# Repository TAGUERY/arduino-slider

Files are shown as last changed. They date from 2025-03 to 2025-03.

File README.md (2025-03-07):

# Template Projet Arduino

[Vidéo démonstration](https://raw.githubusercontent.com/TAGUERY/arduino-slider/main/docs/assets/video-demo.mp4)

`Réalisé par Tristan Montanari
Option Arduino 2025 – COMEM+`

---

## Description

À l'origine, mon projet devait être un slider pour une caméra. Cependant, en prenant en compte le temps disponible, le matériel et le budget, j'ai décidé de conserver l'idée du slider mais en l'adaptant à un usage en salle de classe.

[Vidéo 1 qui m'a inspiré pour la conception](https://www.youtube.com/watch?v=4Rm1vJ67MkA&t=10s&ab_channel=GRINwood)
[Vidéo 2](https://www.youtube.com/watch?v=fR_-R2bS9ag&t=449s&ab_channel=FilmRiot)

Ce dispositif est placé sous une corbeille à papier. Les étudiants doivent essayer de jeter leurs feuilles dans la poubelle de recyclage, mais avec un défi supplémentaire : la plateforme bouge aléatoirement de droite à gauche. Elle effectue des allers-retours entre deux extrémités et deux capteurs permettent de relancer son mouvement lorsqu’elle atteint un bord.

## Documentation

Retrouvez la documentation dans le dossier [Docs](https://github.com/TAGUERY/arduino-slider/tree/main/docs)

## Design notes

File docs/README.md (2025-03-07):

# Documentation  

## Recherche et conception  

`À l’origine, je voulais créer un slider motorisé pour une caméra. Mais en prenant en compte le temps à disposition, le matériel et le budget, j’ai décidé d’adapter l’idée tout en gardant le concept du slider.`  

`Ce projet est conçu pour être installé sous une corbeille à papier. L’objectif est d’ajouter un défi lors du recyclage des feuilles : au lieu de simplement jeter le papier, les utilisateurs doivent viser une poubelle qui bouge. Le slider se déplace de manière aléatoire de droite à gauche, ce qui ajoute une difficulté supplémentaire.`  

`Le mouvement est contrôlé par un moteur et des capteurs. Il effectue des allers-retours entre deux extrémités, et un capteur détecte lorsque la plateforme atteint un bord pour la faire repartir dans l’autre sens.`  

Construction (voir les images en suivant les étapes):
1. Couper le bois en 3 parties : 2x 20x10 cm et 1x 23x20 cm.
2. Percer deux trous parallèles à mi-hauteur, d’un diamètre de 1 cm, avec un espacement d’environ 15 cm.
3. Planter 4 clous à 12 cm chacun sur la plateforme (planche de 23x20 cm) pour guider celle-ci le long des deux tubes.
4. Fixer 2 équerres (du côté des clous) pour y placer les deux capteurs avec du double-face, en veillant à ce qu’ils soient orientés vers l’extérieur.
5. Insérer les tiges dans les 2 planches de 20x10 cm.
6. Fixer les équerres et installer le moteur (écart de 31 mm entre les deux pas de vis, si c'est un NEMA 17).
7. Planter un clou avec une roue crantée, en s’assurant qu’elle puisse tourner librement.
8. Sur le profil de la plateforme, fixer une équerre avec la pince à courroie.
9. Installer la courroie. Si elle est trop courte, faire passer les tubes à travers la planche latérale pour rapprocher les deux planches.
10. Remplacer les fils des capteurs par des fils d’au moins 1 mètre, afin qu’ils puissent se déplacer avec la plateforme.

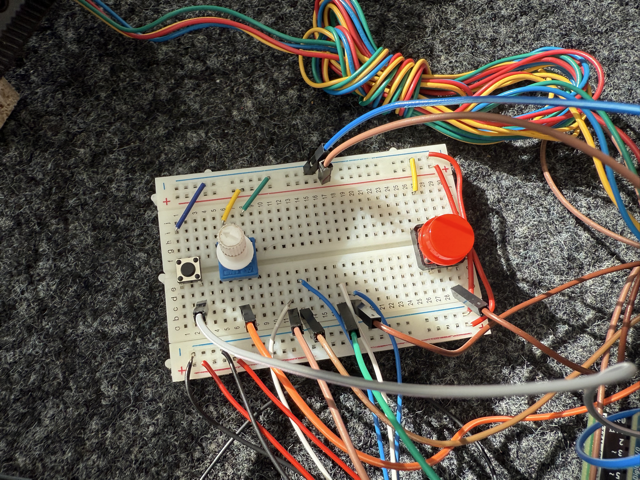
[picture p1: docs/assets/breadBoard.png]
Breadboard
  
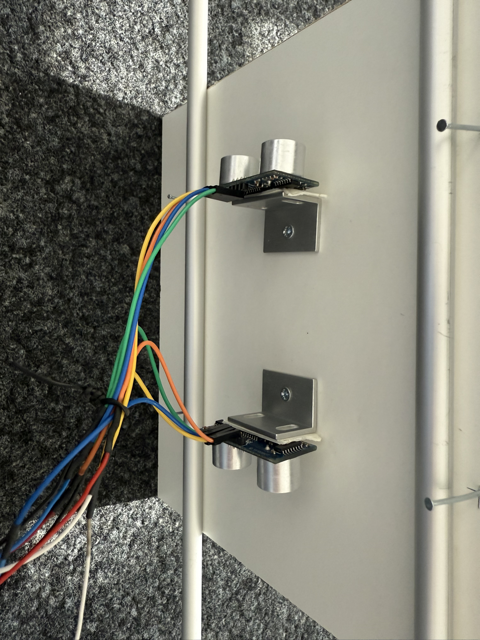
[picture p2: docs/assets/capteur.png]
capteurs sous la plateforme
  
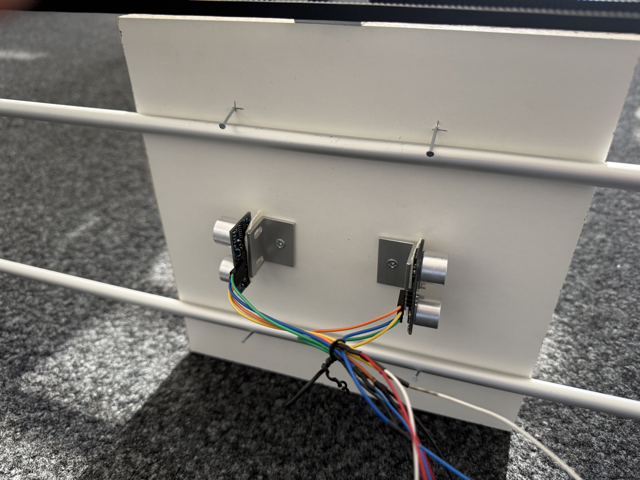
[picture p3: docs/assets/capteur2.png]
autre angle des capteurs sous la plateforme
  
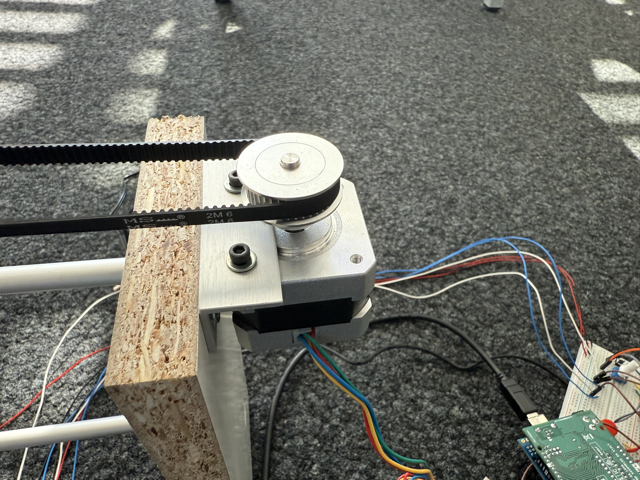
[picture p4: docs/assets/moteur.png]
moteur avec le couroie
  
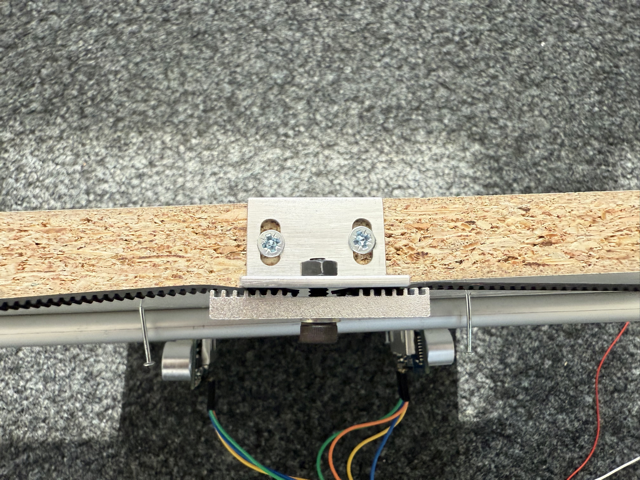
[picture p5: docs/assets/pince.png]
couroie attachée à la plateforme
  
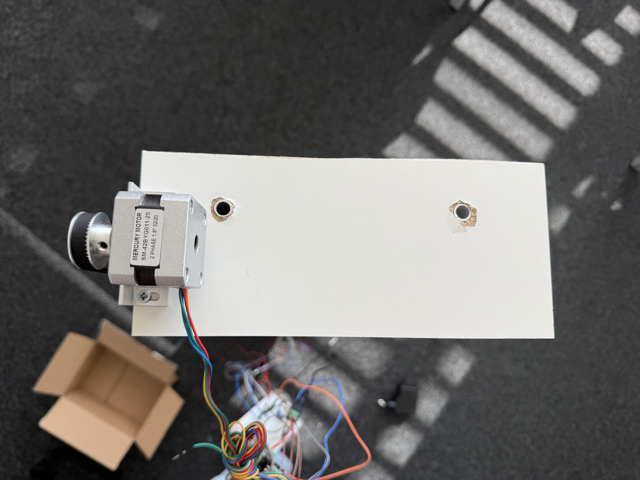
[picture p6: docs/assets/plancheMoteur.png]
moteur vissé à la planche principale
  

---

## Circuit électronique  

`Le circuit est basé sur un Arduino Uno, un moteur pas à pas et des capteurs de distance.`  

---

### Schéma  

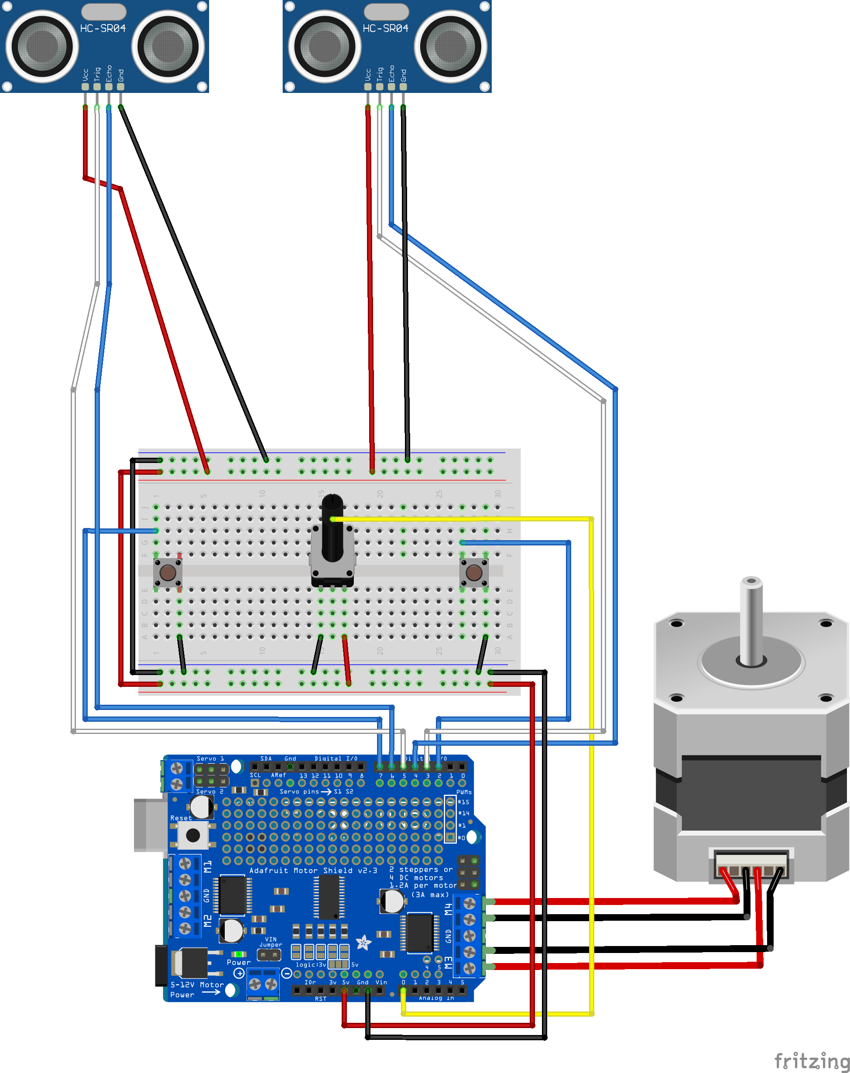
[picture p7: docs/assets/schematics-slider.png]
Schéma du circuit
  

`Attention au raccordement des fils du moteur, il faut contrôler le branchement correct des câbles avec un multimètre.`  

---

### BOM  

| Réf | Composant | Quantité | Description | Fournisseur / Lien |
| --- | --- | --- | --- | --- |
| 1 | Arduino Uno R3 | 1 | Microcontrôleur ATmega328P | [Arduino](https://store.arduino.cc/products/arduino-uno-rev3) |
| 2 | Breadboard | 1 | Plaque de prototypage | |
| 3 | HC-SR04 Sensor | 2 | Capteur de distance pour détecter les bords | [Distrelec](https://www.distrelec.ch/en/hc-sr04-ultrasonic-distance-sensor-sparkfun-electronics-sen-15569/p/30160395) |
| 4 | Alimentation 12 V | 1 | Alimentation pour le moteur | |
| 5 | Shield Adafruit V3 | 1 | Shield pour contrôler le moteur | [Digikey](https://www.digikey.ch/de/products/detail/adafruit-industries-llc/2601/9452124?productid=9452124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) |
| 6 | Moteur pas à pas Mercury Motor SM 42BYG011-25 | 1 | Moteur pour déplacer le slider | [Digikey](https://www.distrelec.ch/de/bipolarer-schrittmotor-nema-17-12v-sparkfun-electronics-sm-42byg011-25/p/30145493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) |
| 7 | Poulie Z40 GT2-6 (5 mm) | 1 | Poulie pour la courroie GT2 | [Bastelgarage](https://www.bastelgarage.ch/poulie-z40-gt2-6-avec-un-alesage-de-5mm-et-un-siege-de-16mm) |
| 8 | Kit de réparation de courroie GT2 (2000 mm) | 1 | Courroie GT2 pour le déplacement du slider | [Bastelgarage](https://www.bastelgarage.ch/kit-de-reparation-de-courroie-gt2-2000mm) |
| 9 | Poulie Z20 GT2-6 (5 mm) | 1 | Deuxième poulie GT2 | [Bastelgarage](https://www.bastelgarage.ch/poulie-z20-gt2-6-avec-alesage-de-5mm-et-siege-de-16mm) |
| 10  | Pince à courroie GT2 (9 mm) | 1 | Fixation de la courroie | [Bastelgarage](https://www.bastelgarage.ch/pince-a-courroie-gt2-9mm) |
| 11  | Vis M3 | 2 | Fixation du moteur |  |
| 12  | Rondelles | 5 | Renforts pour la fixation |  |
| 13  | Équerres | 5 | Support pour la structure |  |
| 14  | Tubes | 2 | barres pour faire glisser la plateforme | [Jumbo](https://www.jumbo.ch/fr/gros-outillage-atelier/ferrures-boites-aux-lettres/profiles/profiles-en-aluminium/alfer-tube-rond-en-aluminium---10-mm--1-m/p/3198038) |
| 15  | Planche compressée | 1 | 20cm X 63cm | [Jumbo](https://www.jumbo.ch/fr/construction-renovation/bois/decoupe-du-bois/c/060201) |

## Programme  

### Bibliothèques utilisées  
- **Wire.h** : Communication I2C utilisée par le Shield moteur.  
- **Adafruit_MotorShield.h** : Gestion du moteur pas à pas via le Shield Adafruit.  

### Structure du programme  
- **Initialisation** :  
  - Configuration des broches, des boutons et des capteurs à ultrasons.  
  - Vérification de la connexion du Shield moteur.  
  - Définition de la vitesse du moteur.  

- **Fonctionnement principal** :  
  - **Gestion des boutons** : Détection avec anti-rebond pour le changement de direction et l'activation/désactivation du moteur.  
  - **Contrôle de la vitesse** : Lecture d'un potentiomètre et adaptation de la vitesse en temps réel.  
  - **Changement de direction** : Automatique basé sur une logique de changement aléatoire ou en fonction des capteurs.  
  - **Capteurs à ultrasons** : Détection d'obstacles pour modifier le sens du moteur si la distance est inférieure à un seuil défini.  
  - **Exécution du moteur** : Mouvement du moteur pas à pas avec gestion du sens et libération du moteur lorsqu'il est éteint.  

### Particularités  
- **Détection d'obstacles** avec deux capteurs **HC-SR04**, permettant d'inverser la direction du moteur.  
- **Changement aléatoire de direction** après un intervalle de temps défini.  
- **Contrôle manuel** via deux boutons pour changer la direction ou activer/désactiver le moteur.  
- **Réglage dynamique de la vitesse** avec un potentiomètre.  

### Points d'amélioration  
- Ajouter une gestion plus fine des courbes de vitesse pour éviter les à-coups.  
- Optimiser la gestion des interruptions pour la lecture des capteurs.  
- Le système de glissement sur les deux barres en acier pour fluidifier les changements de direction.  

---

## Roadmap  

`- Ajouter un signal sonore ou une LED pour indiquer qu’un papier a bien été lancé dans la corbeille.` 

`- Mettre en place un petit écran LCD avec la sélection de mode de jeux et l'affichage de la vitesse.` 

---

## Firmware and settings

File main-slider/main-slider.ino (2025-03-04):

#include <Wire.h>
#include <Adafruit_MotorShield.h>

// Initialisation du shield moteur et du moteur pas à pas
Adafruit_MotorShield AFMS = Adafruit_MotorShield();
Adafruit_StepperMotor *myMotor = AFMS.getStepper(200, 2);

// Définition des broches et variables pour les boutons
const int speedPin = A0;
const int buttonPins[] = {13, 2};
const int btnNb = sizeof(buttonPins) / sizeof(buttonPins[0]);

int buttonStates[btnNb];
int lastButtonStates[btnNb];
unsigned long lastDebounceTimes[btnNb] = {0};
const unsigned long DEBOUNCE_DELAY = 50; // Temps de filtrage anti-rebond

// Variables de contrôle du moteur
int speedTogglerValue = 0;
int lastSpeedTogglerValue = -1;
bool motorState = false;
bool motorDirection = true;
int motorSpeed = 0;

int tempoRandom = false;

// Capteurs à ultrasons
const int trigPinBis = 3;
const int echoPinBis = 4;
const int trigPin = 5;
const int echoPin = 6;

long duration, durationBis;
int distance, distanceBis;
unsigned long lastChangeTime = 0;
const unsigned long changeDelay = 1000;

unsigned long lastRandomChange = 0;
const unsigned long randomChangeInterval = 800;

void setup()
{
  Serial.begin(9600);
  while (!Serial)
    ;

  // Configuration des boutons
  for (int i = 0; i < btnNb; i++)
  {
    pinMode(buttonPins[i], INPUT_PULLUP);
    lastButtonStates[i] = HIGH;
    buttonStates[i] = HIGH;
  }

  // Initialisation du shield moteur
  if (!AFMS.begin())
  {
    Serial.println("Motor Shield not found.");
    while (1)
      ;
  }

  myMotor->setSpeed(10); // Vitesse initiale du moteur

  // Configuration des capteurs à ultrasons
  pinMode(trigPin, OUTPUT);
  pinMode(echoPin, INPUT);
  pinMode(trigPinBis, OUTPUT);
  pinMode(echoPinBis, INPUT);
}

// Gestion des boutons avec anti-rebond
void button()
{
  for (int i = 0; i < btnNb; i++)
  {
    int currentButtonState = digitalRead(buttonPins[i]);

    if (currentButtonState != lastButtonStates[i])
    {
      lastDebounceTimes[i] = millis();
    }

    if ((millis() - lastDebounceTimes[i]) > DEBOUNCE_DELAY)
    {
      if (currentButtonState != buttonStates[i])
      {
        buttonStates[i] = currentButtonState;
        if (buttonStates[i] == LOW)
        {
          if (i == 0)
            changeDirection(); // Bouton 1 : changement de direction
          if (i == 1)
            onoffMotor(); // Bouton 2 : allumer/éteindre le moteur
        }
      }
    }
    lastButtonStates[i] = currentButtonState;
  }
}

// Lecture et mise à jour de la vitesse via un potentiomètre
void speed()
{
  int newSpeedTogglerValue = analogRead(speedPin);

  if (abs(newSpeedTogglerValue - lastSpeedTogglerValue) > 5)
  {
    speedTogglerValue = newSpeedTogglerValue;
    lastSpeedTogglerValue = newSpeedTogglerValue;

    int newSpeed = map(speedTogglerValue, 0, 1023, 10, 200);
    if (newSpeed != motorSpeed)
    {
      motorSpeed = newSpeed;
      Serial.print("Vitesse : ");
      Serial.println(motorSpeed);
      myMotor->setSpeed(motorSpeed);
    }
  }
}

// Inverse la direction du moteur
void changeDirection()
{
  motorDirection = !motorDirection;
}

// Changement aléatoire de direction après un certain intervalle
void randomDirectionChange()
{
  if ((millis() - lastChangeTime) > 4000)
  {
    if (millis() - lastRandomChange > randomChangeInterval)
    {
      motorDirection = random(0, 2);
      lastRandomChange = millis();
    }
  }
}

// Mesure la distance avec le premier capteur et change la direction si un obstacle est proche
void measureDistance()
{
  digitalWrite(trigPin, LOW);
  delayMicroseconds(2);
  digitalWrite(trigPin, HIGH);
  delayMicroseconds(10);
  digitalWrite(trigPin, LOW);

  duration = pulseIn(echoPin, HIGH);
  distance = duration * 0.034 / 2;

  if (distance < 10 && (millis() - lastChangeTime) > changeDelay)
  {
    Serial.println(distance);
    changeDirection();
    lastChangeTime = millis();
  }
}

// Mesure la distance avec le deuxième capteur et change la direction si un obstacle est proche
void measureDistanceBis()
{
  digitalWrite(trigPinBis, LOW);
  delayMicroseconds(2);
  digitalWrite(trigPinBis, HIGH);
  delayMicroseconds(10);
  digitalWrite(trigPinBis, LOW);

  durationBis = pulseIn(echoPinBis, HIGH);
  distanceBis = durationBis * 0.034 / 2;

  if (distanceBis < 10 && (millis() - lastChangeTime) > changeDelay)
  {
    Serial.println(distanceBis);
    changeDirection();
    lastChangeTime = millis();
  }
}

// Gère les différentes actions du moteur
void runMotor()
{
  button();
  speed();
  if (!tempoRandom)
  {
    randomDirectionChange();
  }
  measureDistance();
  measureDistanceBis();

  if (motorState)
  {
    int direction = motorDirection ? FORWARD : BACKWARD;
    myMotor->step(10, direction, DOUBLE);
  }
}

// Active ou désactive le moteur
void onoffMotor()
{
  motorState = !motorState;
  Serial.println(motorState ? "Moteur ALLUMÉ" : "Moteur ÉTEINT");
  if (!motorState)
  {
    myMotor->release(); // Libération du moteur quand il est éteint
  }
}

// Boucle principale
void loop()
{
  runMotor();
}

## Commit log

2025-03-04 inital commit + fritzing + .ino
    [slider-arduino.fzz]
2025-03-04 modification selon template de projet initial
    [schematics-slider.fzz]
2025-03-04 début de la complétion des readme
2025-03-04 correction lien readme principal
    [main-slider.ino]
2025-03-06 explication construction plateforme2
2025-03-07 add schema img
    [schematics-slider.fzz]
2025-03-07 push final
    [schematics-slider.fzz]
